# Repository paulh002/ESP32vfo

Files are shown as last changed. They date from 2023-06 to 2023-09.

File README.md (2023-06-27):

# ESP32vfo

Disclaimer -->  source code developement is in progress not all functions are migrated from the old version!

Source code for VFO-ESP32-Si5351 v3 
A new PCB size 10cm x 5.6 cm 4 layers this can be lowcost produced.
Supports 1 optical encoder and multiple rotary encoders through a pcf8574

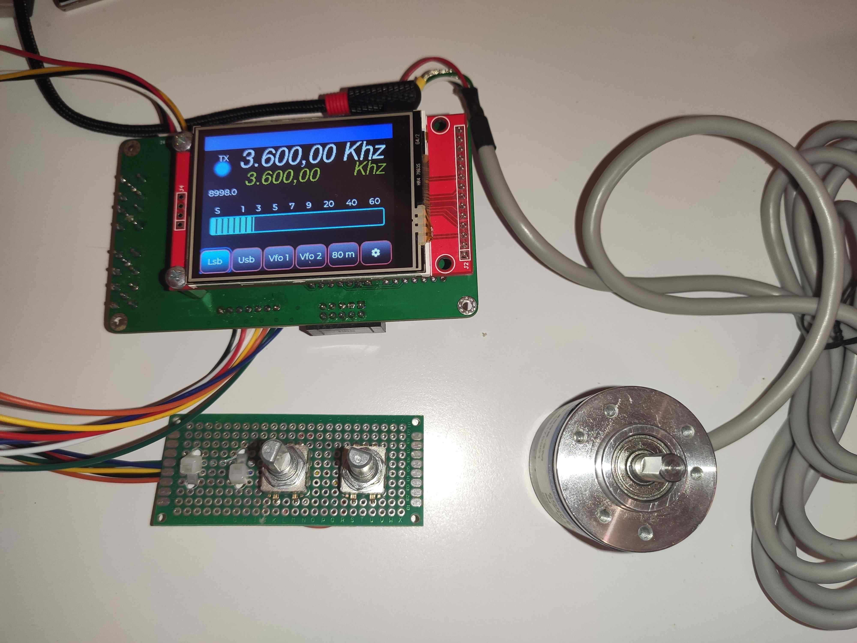
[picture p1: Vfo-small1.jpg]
VFO


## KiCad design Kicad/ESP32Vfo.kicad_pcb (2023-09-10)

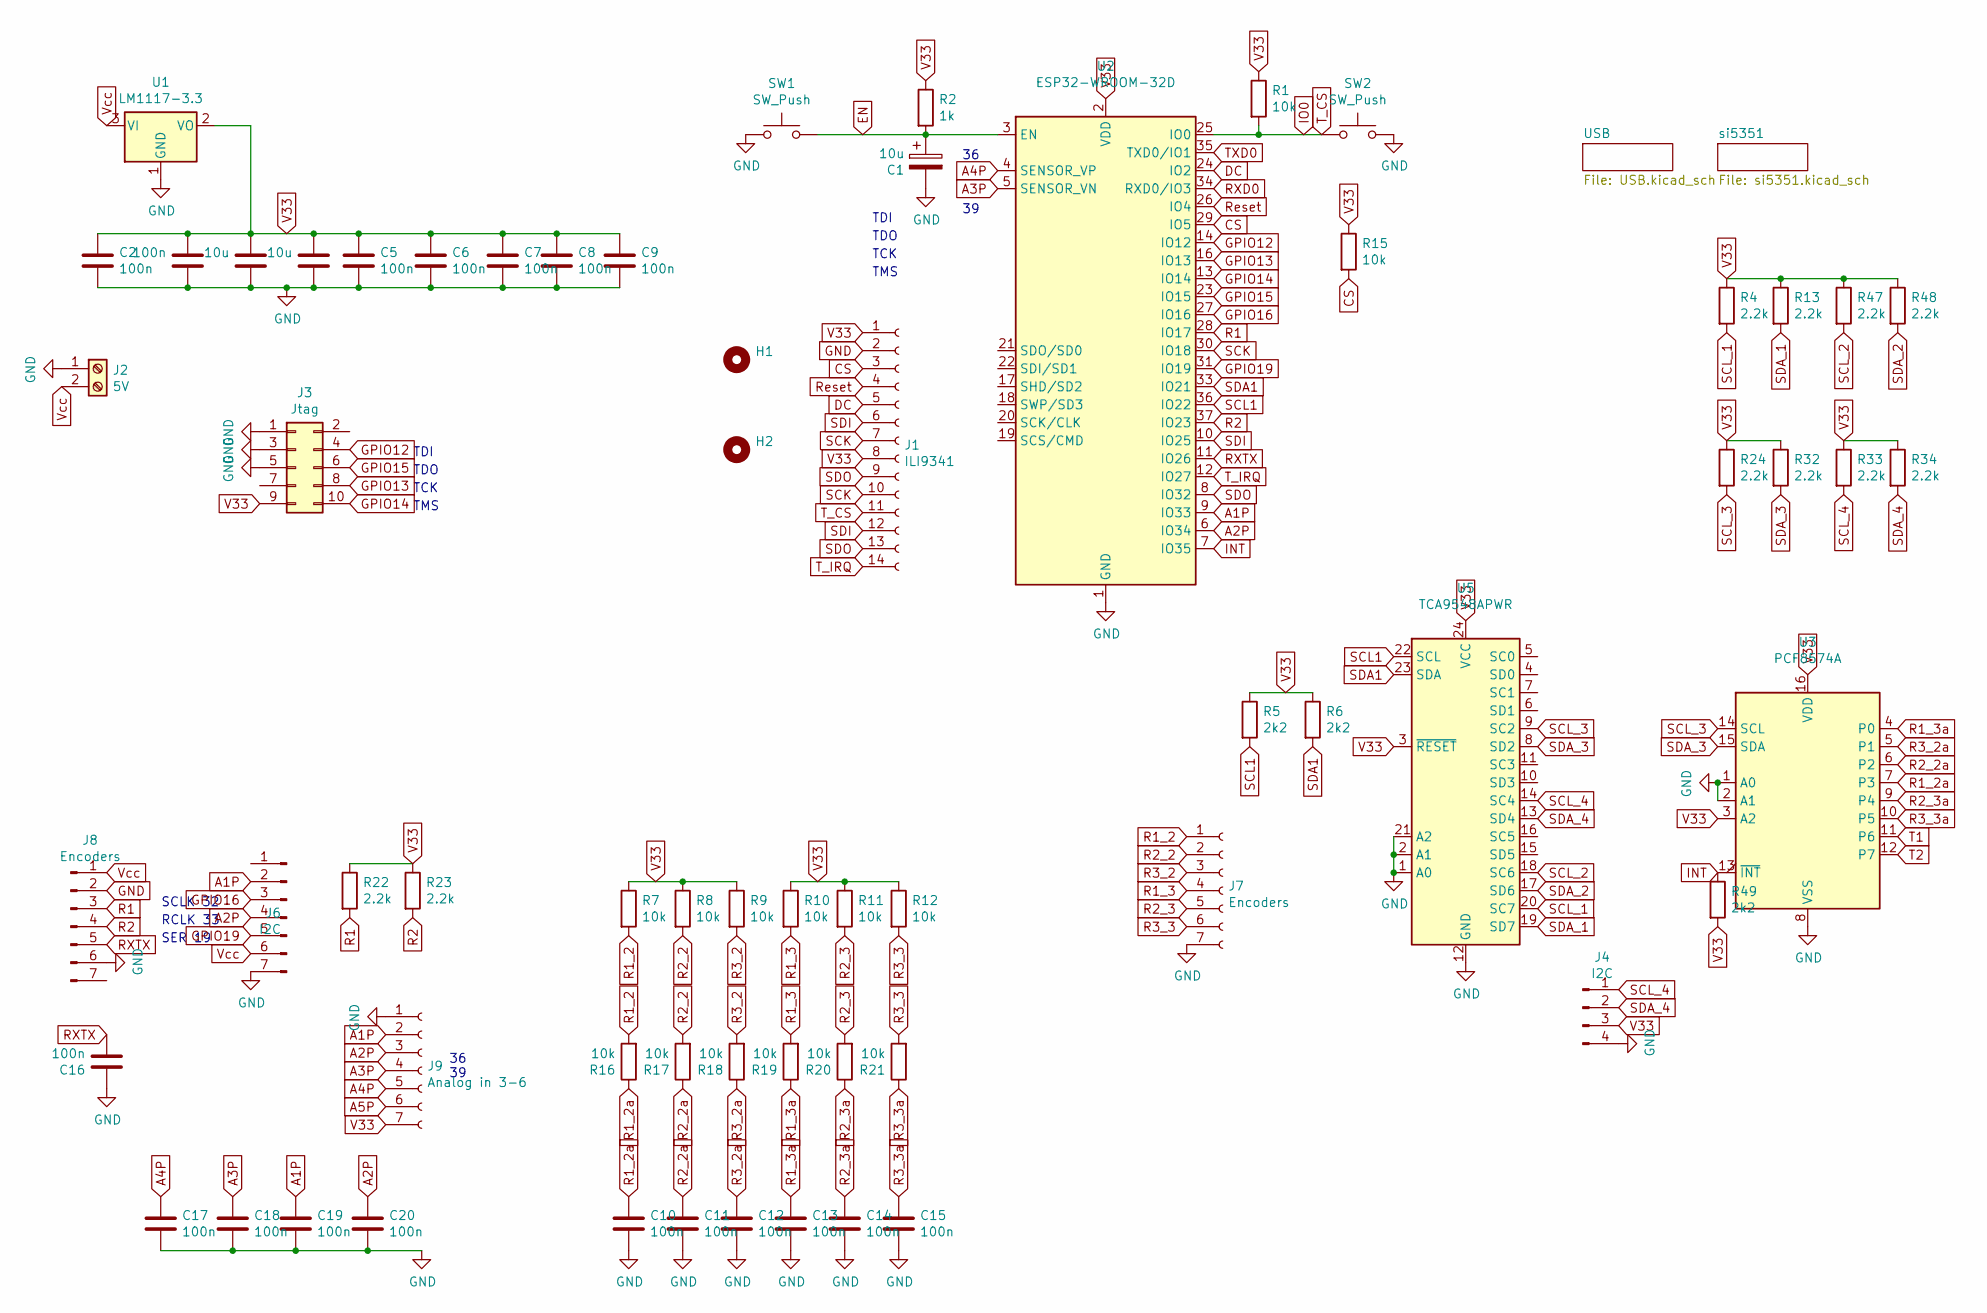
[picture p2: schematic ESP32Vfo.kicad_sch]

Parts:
C1, C4: 10u; C_1206_3216Metric_Pad1.42x1.75mm_HandSolder
C2, C3, C5, C6, C7, C8, C9, C10, C11, C12, C13, C14, C15, C16, C17, C18, C19, C20: 100n; C_0805_2012Metric
C34: 10u; C_0805_2012Metric
H1, H2: MountingHole_3.2mm_M3
J1: ILI9341; PinSocket_1x14_P2.54mm_Vertical
J2: 5V; TerminalBlock_MetzConnect_Type011_RT05502HBWC_1x02_P5.00mm_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
J3: Jtag; PinSocket_2x05_P2.54mm_Vertical
J4: I2C; JST_PH_S4B-PH-SM4-TB_1x04-1MP_P2.00mm_Horizontal
J6: I2C; PinSocket_1x07_P2.54mm_Vertical
J7, J8: Encoders; PinSocket_1x07_P2.54mm_Vertical
J9: Analog in 3-6; PinSocket_1x07_P2.54mm_Vertical
R1, R7, R8, R9, R10, R11, R12, R15, R16, R17, R18, R19, R20, R21: 10k; R_0805_2012Metric
R2: 1k; R_0805_2012Metric
R4, R13, R22, R23, R24, R32, R33, R34, R47, R48: 2.2k; R_0805_2012Metric
R5, R6, R49: 2k2; R_0805_2012Metric
SW1, SW2: SW_Push; TS-1088R-02526
U1: LM1117-3.3; SOT-223-3_TabPin2
U2: ESP32-WROOM-32D; ESP32-WROOM-32
U3: PCF8574A; SOP-16_7.5x10.4mm_P1.27mm
U5: TCA9548APWR; TSSOP-24_4.4x7.8mm_P0.65mm

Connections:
A1P: C19.2, J6.2, J9.2, U2.9 (IO33)
A2P: C20.2, J6.4, J9.3, U2.6 (IO34)
A3P: C18.2, J9.4, U2.5 (SENSOR_VN)
A4P: C17.2, J9.5, U2.4 (SENSOR_VP)
A5P: J9.6
CS: J1.3, R15.2, U2.29 (IO5)
DC: J1.5, U2.24 (IO2)
EN: C1.1, R2.2, SW1.2, U2.3 (EN); also elsewhere on the board
GND: C1.2, C2.1, C3.2, C4.2, C5.1, C6.1, C7.1, C8.1, C9.1, C10.1, C11.1, C12.1, C13.1, C14.1, C15.1, C16.2, C17.1, C18.1, C19.1, C20.1, C34.2, J1.2, J2.1, J3.1, J3.3, J3.5, J4.4, J6.7, J7.7, J8.2, J8.6, J9.1, SW1.1, SW2.2, U1.1 (GND), U2.1 (GND), U2.15 (GND), U2.38 (GND), U2.39 (GND), U3.1 (A0), U3.2 (A1), U3.8 (VSS), U5.1 (A0), U5.2 (A1), U5.12 (GND), U5.21 (A2); also elsewhere on the board
GPIO12: J3.4, U2.14 (IO12)
GPIO13: J3.8, U2.16 (IO13)
GPIO14: J3.10, U2.13 (IO14)
GPIO15: J3.6, U2.23 (IO15)
GPIO16: J6.3, U2.27 (IO16)
GPIO19: J6.5, U2.31 (IO19)
INT: R49.1, U2.7 (IO35), U3.13 (~INT)
IO0: J1.11, R1.2, SW2.1, U2.25 (IO0); also elsewhere on the board
R1: J8.3, R22.2, U2.28 (IO17)
R1_2: J7.1, R7.2, R16.2
R1_2a: C10.2, R16.1, U3.7 (P3)
R1_3: J7.4, R10.2, R19.2
R1_3a: C13.2, R19.1, U3.4 (P0)
R2: J8.4, R23.2, U2.37 (IO23)
R2_2: J7.2, R8.2, R17.2
R2_2a: C11.2, R17.1, U3.6 (P2)
R2_3: J7.5, R11.2, R20.2
R2_3a: C14.2, R20.1, U3.9 (P4)
R3_2: J7.3, R9.2, R18.2
R3_2a: C12.2, R18.1, U3.5 (P1)
R3_3: J7.6, R12.2, R21.2
R3_3a: C15.2, R21.1, U3.10 (P5)
RXD0: U2.34 (RXD0/IO3); also elsewhere on the board
RXTX: C16.1, J8.5, U2.11 (IO26); also elsewhere on the board
Reset: J1.4, U2.26 (IO4)
SCK: J1.7, J1.10, U2.30 (IO18)
SCL1: R5.2, U2.36 (IO22), U5.22 (SCL)
SCL_1: R4.2, U5.20 (SC7); also elsewhere on the board
SCL_2: R47.2, U5.18 (SC6); also elsewhere on the board
SCL_3: R24.2, U3.14 (SCL), U5.9 (SC2)
SCL_4: J4.1, R33.2, U5.14 (SC4)
SDA1: R6.2, U2.33 (IO21), U5.23 (SDA)
SDA_1: R13.2, U5.19 (SD7); also elsewhere on the board
SDA_2: R48.2, U5.17 (SD6); also elsewhere on the board
SDA_3: R32.2, U3.15 (SDA), U5.8 (SD2)
SDA_4: J4.2, R34.2, U5.13 (SD4)
SDI: J1.6, J1.12, U2.10 (IO25)
SDO: J1.9, J1.13, U2.8 (IO32)
T1: U3.11 (P6); also elsewhere on the board
T2: U3.12 (P7); also elsewhere on the board
TXD0: U2.35 (TXD0/IO1); also elsewhere on the board
T_IRQ: J1.14, U2.12 (IO27)
V33: C2.2, C3.1, C4.1, C5.2, C6.2, C7.2, C8.2, C9.2, C34.1, J1.1, J1.8, J3.9, J4.3, J9.7, R1.1, R2.1, R4.1, R5.1, R6.1, R7.1, R8.1, R9.1, R10.1, R11.1, R12.1, R13.1, R15.1, R22.1, R23.1, R24.1, R32.1, R33.1, R34.1, R47.1, R48.1, R49.2, U1.2 (VO), U2.2 (VDD), U3.3 (A2), U3.16 (VDD), U5.3 (~RESET), U5.24 (VCC); also elsewhere on the board
Vcc: J2.2, J6.6, J8.1, U1.3 (VI); also elsewhere on the board

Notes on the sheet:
TDI
TDO
TMS
RCLK 33
SER 19
TCK
36 39
SCLK 32

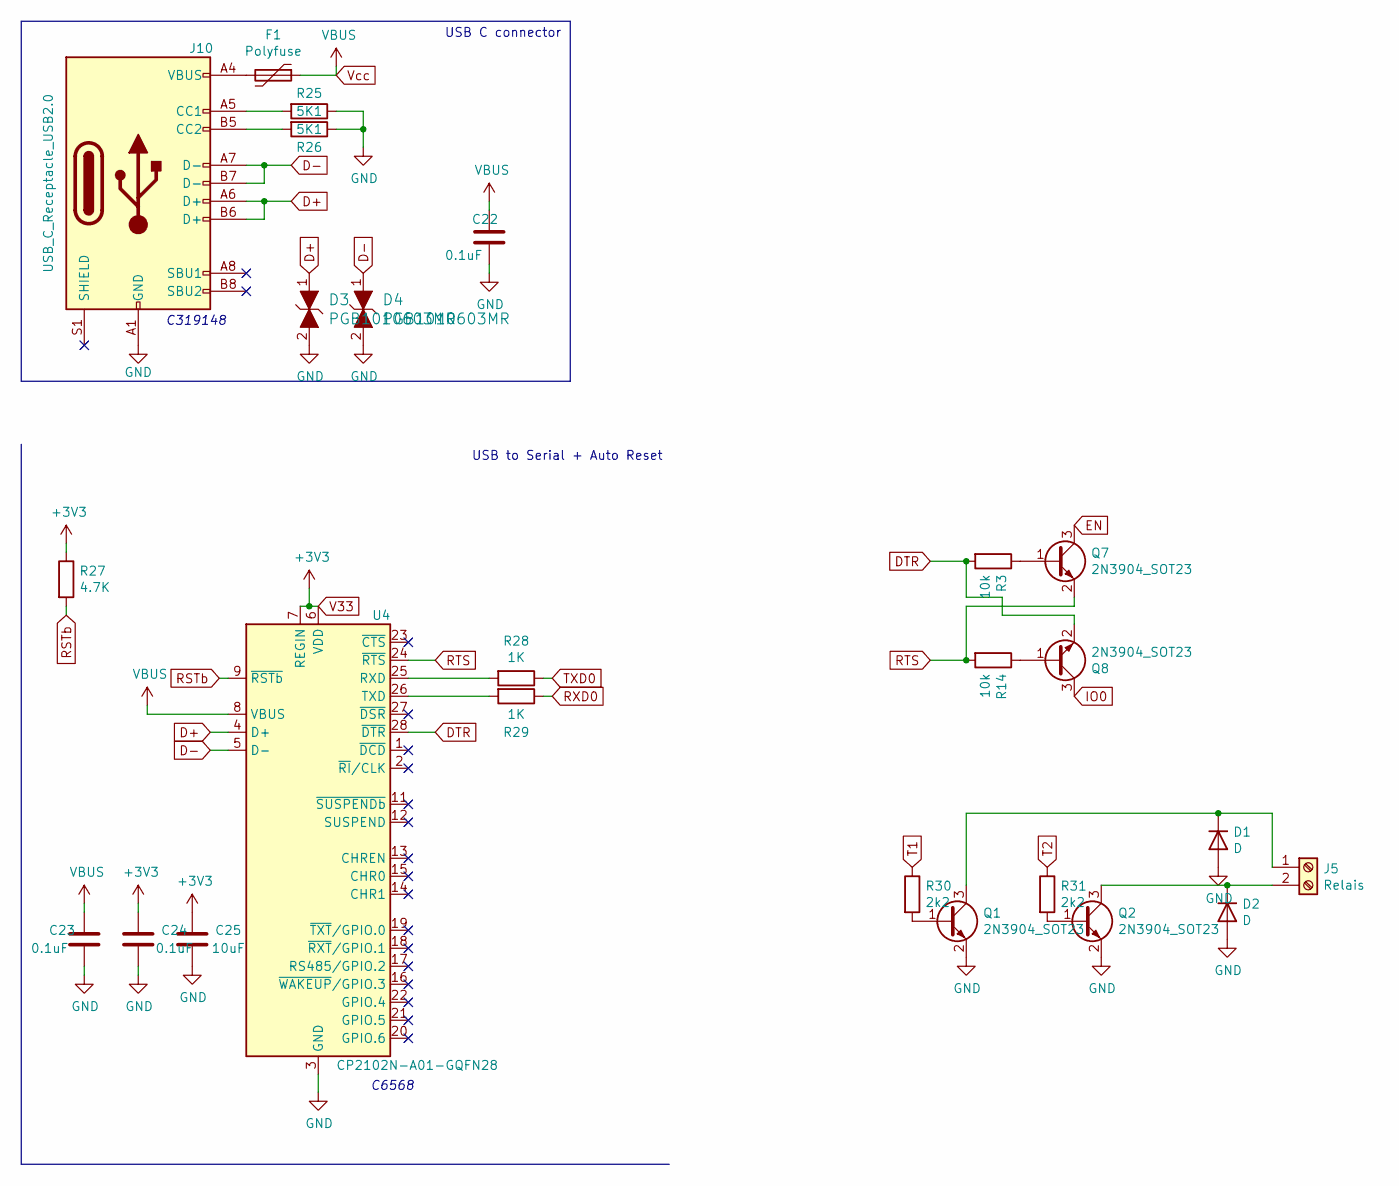
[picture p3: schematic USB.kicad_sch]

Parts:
C22, C23, C24: 0.1uF; C_0805_2012Metric
C25: 10uF; C_0805_2012Metric
D1, D2: D; D_SOD-323
D3, D4: PGB1010603MR; 0603; MPN PGB1010603MR; Digi-Key_PN F2594CT-ND
F1: Polyfuse; Fuse_0805_2012Metric
J5: Relais; PinHeader_1x02_P2.54mm_Vertical
J10: USB_C_Receptacle_USB2.0; USB_C_Receptacle_XKB_U262-16XN-4BVC11
Q1, Q2, Q7, Q8: 2N3904_SOT23; SOT-23
R3, R14: 10k; R_0805_2012Metric
R25, R26: 5K1; R_0805_2012Metric
R27: 4.7K; R_0805_2012Metric
R28, R29: 1K; R_0805_2012Metric
R30, R31: 2k2; R_0805_2012Metric
U4: CP2102N-A01-GQFN28; QFN-28-1EP_5x5mm_P0.5mm_EP3.35x3.35mm

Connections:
D+: D3.1, J10.A6 (D+), J10.B6 (D+), U4.4 (D+)
D-: D4.1, J10.A7 (D-), J10.B7 (D-), U4.5 (D-)
DTR: Q8.2 (E), R3.2, U4.28 (~DTR)
EN: Q7.3 (C); also elsewhere on the board
GND: C22.2, C23.2, C24.2, C25.2, D1.2 (A), D2.2 (A), D3.2, D4.2, J10.A1 (GND), J10.A12 (GND), J10.B1 (GND), J10.B12 (GND), Q1.2 (E), Q2.2 (E), R25.1, R26.1, U4.3 (GND), U4.29 (GND); also elsewhere on the board
IO0: Q8.3 (C); also elsewhere on the board
unnamed: D1.1 (K), J5.1, Q1.3 (C)
unnamed: D2.1 (K), J5.2, Q2.3 (C)
unnamed: F1.2, J10.A4 (VBUS), J10.A9 (VBUS), J10.B4 (VBUS), J10.B9 (VBUS)
unnamed: J10.A5 (CC1), R25.2
unnamed: J10.B5 (CC2), R26.2
unnamed: Q1.1 (B), R30.2
unnamed: Q2.1 (B), R31.2
unnamed: Q7.1 (B), R3.1
unnamed: Q8.1 (B), R14.1
unnamed: R28.2, U4.25 (RXD)
unnamed: R29.2, U4.26 (TXD)
RSTb: R27.2, U4.9 (~RSTb)
RTS: Q7.2 (E), R14.2, U4.24 (~RTS)
RXD0: R29.1; also elsewhere on the board
T1: R30.1; also elsewhere on the board
T2: R31.1; also elsewhere on the board
TXD0: R28.1; also elsewhere on the board
V33: C24.1, C25.1, R27.1, U4.6 (VDD), U4.7 (REGIN); also elsewhere on the board
Vcc: C22.1, C23.1, F1.1, U4.8 (VBUS); also elsewhere on the board

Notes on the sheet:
C319148
USB C connector
USB to Serial + Auto Reset
C6568

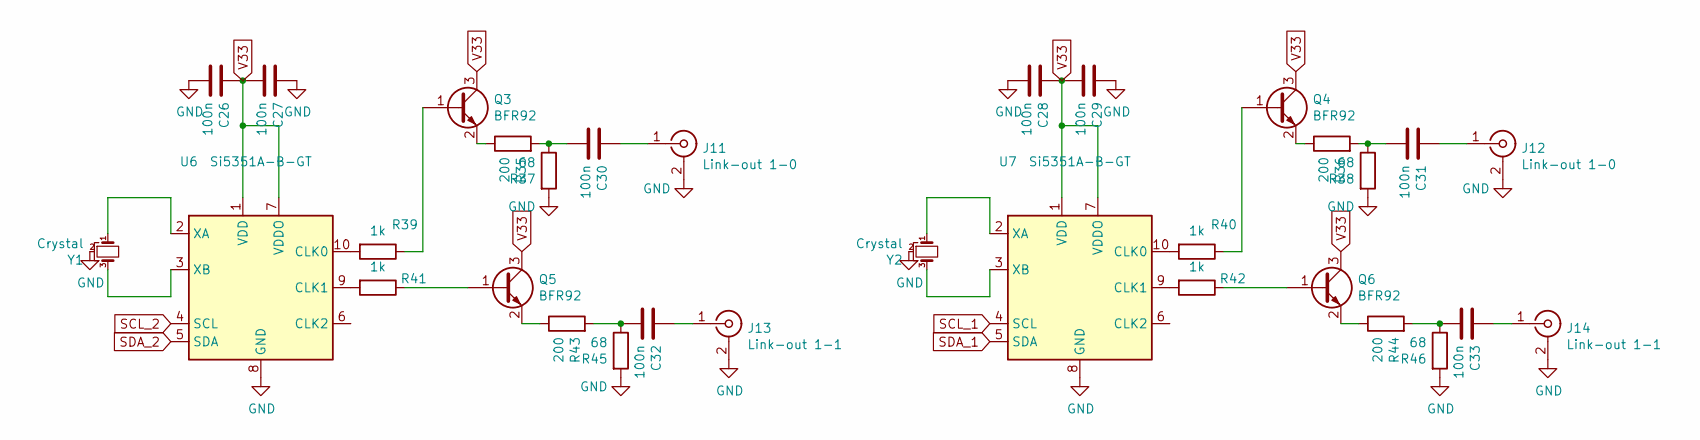
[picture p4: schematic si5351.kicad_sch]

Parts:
C26, C27, C28, C29, C30, C31, C32, C33: 100n; C_0805_2012Metric
J11, J12: Link-out 1-0; SMA_Amphenol_132134_Vertical
J13, J14: Link-out 1-1; SMA_Amphenol_132134_Vertical
Q3, Q4, Q5, Q6: BFR92; SOT-23
R35, R36, R43, R44: 200; R_0805_2012Metric
R37, R38, R45, R46: 68; R_0805_2012Metric
R39, R40, R41, R42: 1k; R_0805_2012Metric
U6, U7: Si5351A-B-GT; MSOP-10_3x3mm_P0.5mm
Y1, Y2: Crystal; Crystal_SMD_TXC_7M-4Pin_3.2x2.5mm_HandSoldering

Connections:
GND: C26.1, C27.2, C28.1, C29.2, J11.2 (Ext), J12.2 (Ext), J13.2 (Ext), J14.2 (Ext), R37.2, R38.2, R45.2, R46.2, U6.8 (GND), U7.8 (GND), Y1.2, Y2.2; also elsewhere on the board
unnamed: C30.1, R35.2, R37.1
unnamed: C30.2, J11.1 (In)
unnamed: C31.1, R36.2, R38.1
unnamed: C31.2, J12.1 (In)
unnamed: C32.1, R43.2, R45.1
unnamed: C32.2, J13.1 (In)
unnamed: C33.1, R44.2, R46.1
unnamed: C33.2, J14.1 (In)
unnamed: Q3.1 (B), R39.1
unnamed: Q3.2 (E), R35.1
unnamed: Q4.1 (B), R40.1
unnamed: Q4.2 (E), R36.1
unnamed: Q5.1 (B), R41.1
unnamed: Q5.2 (E), R43.1
unnamed: Q6.1 (B), R42.1
unnamed: Q6.2 (E), R44.1
unnamed: R39.2, U6.10 (CLK0)
unnamed: R40.2, U7.10 (CLK0)
unnamed: R41.2, U6.9 (CLK1)
unnamed: R42.2, U7.9 (CLK1)
unnamed: U6.2 (XA), Y1.1
unnamed: U6.3 (XB), Y1.3
unnamed: U7.2 (XA), Y2.1
unnamed: U7.3 (XB), Y2.3
SCL_1: U7.4 (SCL); also elsewhere on the board
SCL_2: U6.4 (SCL); also elsewhere on the board
SDA_1: U7.5 (SDA); also elsewhere on the board
SDA_2: U6.5 (SDA); also elsewhere on the board
V33: C26.2, C27.1, C28.2, C29.1, Q3.3 (C), Q4.3 (C), Q5.3 (C), Q6.3 (C), U6.1 (VDD), U6.7 (VDDO), U7.1 (VDD), U7.7 (VDDO); also elsewhere on the board

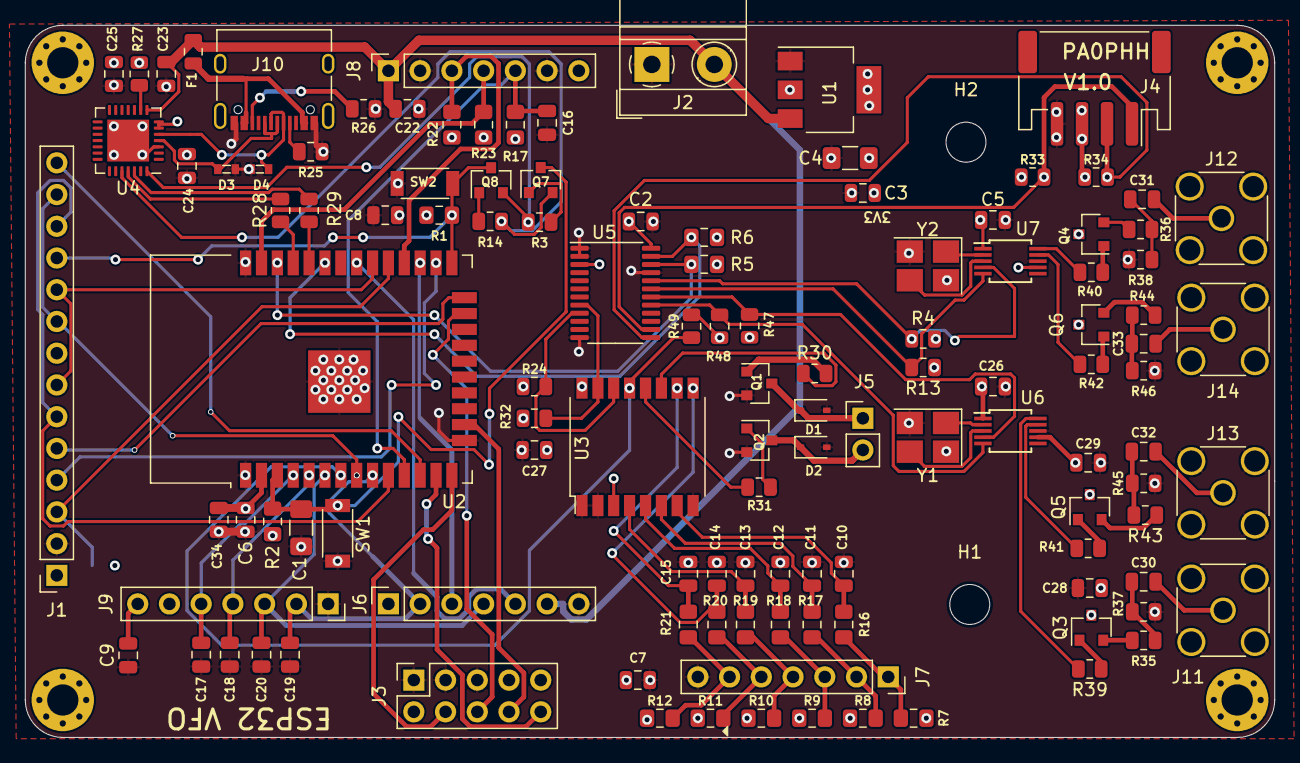
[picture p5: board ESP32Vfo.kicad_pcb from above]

Board: 4 copper layers, 100.0 x 57.0 mm, 127 parts (1 on the bottom side), 92 nets.

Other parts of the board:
H1#2, H2#2: MountingHole_3.2mm_M3
H3, H4: MountingHole; MountingHole_2.5mm_Pad_Via
R17#2: 680; R_0805_2012Metric_Pad1.15x1.40mm_HandSolder

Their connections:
RXTX: R17#2.2; also elsewhere on the board
V33: R17#2.1; also elsewhere on the board

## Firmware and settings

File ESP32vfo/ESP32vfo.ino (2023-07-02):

/*
 Name:		ESP32vfo.ino
 Created:	11/14/2021 1:09:05 PM
 Author:	paulh
*/
#include <WiFi.h>
#include <WiFiClient.h>
#include <lvgl.h>
#include <TFT_eSPI.h>
#include <TCA9548.h>
#include <RotaryEncoder.h>
#include "gui.h"
#include "credentials.h"
#include "measurement.h"
#include "network.h"
#include "io.h"
#include "vfo.h"
#include "_EEPROMAnything.h"
#include "FT891_CAT.h"

SemaphoreHandle_t swrBinarySemaphore = NULL;
SemaphoreHandle_t NetSemaphore = NULL;

#define COLDSTART_REF          0x20 // When started, the firmware examines this "Serial Number
// and enforces factory reset if there is a mismatch.
// Rolling this value is useful if the EEPROM structure has been modified

TFT_eSPI tft = TFT_eSPI(); /* TFT instance */

extern var_t	R;

// the setup function runs once when you press reset or power the board
void setup() {
	Serial.begin(115200); /* prepare for possible serial debug */
	swrBinarySemaphore = xSemaphoreCreateMutex();
	if (swrBinarySemaphore == NULL) {
		Serial.println("Error creating the swrBinarySemaphore");
	}
	net_queue = xQueueCreate(1, sizeof(uint8_t));
	if (net_queue == NULL) {
		Serial.println("Error creating the queue");
	}

	pinMode(TXRX_SWITCH, INPUT);
	pinMode(S_METER, ANALOG);
	pinMode(FWD_METER, ANALOG);
	pinMode(REV_METER, ANALOG);
	adc_init();
	memset(&R, 0, sizeof(R));
	init_io();
	init_vfo(); // load default values for R
	CAT.begin(true);
	start_vfo();
	LoadEEPROM();
	gui.gui_setup();

	R.wifi_onoff = true;
	delay(10);
	if (strlen(R.ssid[0]) == 0) // If no ssid configured take from credentials.h
	{
		for (int i = 0; i < NUMBR_SSID; i++)
		{
			strcpy(R.ssid[i], _ssid[i]);
			strcpy(R.password[i], _password[i]);
		}
	}
	if (R.wifi_onoff)
	{
		for (int i = 0; i < NUMBR_SSID; i++)
		{
			if (strlen(R.ssid[i]))
			{
				Serial.println("Start Wifi");
				if (vfo_network.begin(TRXNET_SERVER))
				{
					return;
				}
			}
		}
	}
}

// the loop function runs over and over again until power down or reset
void loop() {

	if (net_queue)
	{ // Check if we need to start or stop wifi
		uint8_t message;
		if (xQueueReceive(net_queue, &message, 0))
		{
			if (message == 0)
			{
				// stopwifi
				vfo_network.network_stop();
			}
			if (message == 1)
			{
				// startwifi
				vfo_network.begin(TRXNET_SERVER);
			}
		}
	}
	vfo_network.network_loop();
	delay(5);
}


void LoadEEPROM()
{
	uint8_t coldstart;

	EEPROM.begin(sizeof(var_t) + sizeof(uint8_t));

	coldstart = EEPROM.read(0);               // Grab the coldstart byte indicator in EEPROM for
											   // comparison with the COLDSTART_REFERENCE

	Serial.println(String("Coldstart : ") + String(coldstart));

	// Initialize all memories if first upload or if COLDSTART_REF has been modified
	// either through PSWR_A.h or through Menu functions

	if (coldstart == COLDSTART_REF - 1)
	{

		EEPROM_readAnything(1, R);               // Read the stored data
		long  current_frq1[] = { 1800000,3500000,5350000,7000000,10100000,14000000,18068000,21000000,28000000 };
		long  current_frq2[] = { 1800000,3500000,5350000,7000000,10100000,14000000,18068000,21000000,28000000 };

		memcpy(R.current_frq1, current_frq1, sizeof(current_frq1));
		memcpy(R.current_frq2, current_frq2, sizeof(current_frq2));
		return;
	}

	if (coldstart != COLDSTART_REF)
	{
		EEPROM.write(0, COLDSTART_REF);          // COLDSTART_REF in first byte indicates all initialized
		EEPROM_writeAnything(1, R);              // Write default settings into EEPROM
		EEPROM.commit();
	}
	else                                      // EEPROM contains stored data, retrieve the data
	{
		EEPROM_readAnything(1, R);               // Read the stored data
	}
}

void SaveEEPROM()
{
	EEPROM.write(0, COLDSTART_REF);          // COLDSTART_REF in first byte indicates all initialized
	EEPROM_writeAnything(1, R);              // Write default settings into  
	EEPROM.commit();
}

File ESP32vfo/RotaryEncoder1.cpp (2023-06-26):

// -----
// RotaryEncoder.cpp - Library for using rotary encoders.
// This class is implemented for use with the Arduino environment.
//
// Copyright (c) by Matthias Hertel, http://www.mathertel.de
//
// This work is licensed under a BSD 3-Clause style license,
// https://www.mathertel.de/License.aspx.
//
// More information on: http://www.mathertel.de/Arduino
// -----
// Changelog: see RotaryEncoder.h
// -----

#include "RotaryEncoder1.h"
#include "Arduino.h"

#define LATCH0 0 // input state at position 0
#define LATCH3 3 // input state at position 3


// The array holds the values �1 for the entries where a position was decremented,
// a 1 for the entries where the position was incremented
// and 0 in all the other (no change or not valid) cases.

const int8_t KNOBDIR[] = {
    0, -1, 1, 0,
    1, 0, 0, -1,
    -1, 0, 0, 1,
    0, 1, -1, 0};


// positions: [3] 1 0 2 [3] 1 0 2 [3]
// [3] is the positions where my rotary switch detends
// ==> right, count up
// <== left,  count down


// ----- Initialization and Default Values -----

RotaryEncoder::RotaryEncoder(uint8_t address, uint8_t cnt, LatchMode mode, TwoWire* wire)
{
  // Remember Hardware Setup
  _address = address;
  _mode = mode;
  _cnt = cnt;

  // Setup wire
  _wire = wire;
  for (int i = 0; i < max_enc; i++)
  {
      // start with position 0;
      // when not started in motion, the current state of the encoder should be 3
      _oldState[i] = 0x03;
      _position[i] = 0;
      _positionExt[i] = 0;
      _positionExtPrev[i] = 0;
  }
} // RotaryEncoder()


long RotaryEncoder::getPosition(int enc)
{
    if (enc >= 0 && enc < _cnt)
        return _positionExt[enc];
    return -1;
} // getPosition()


RotaryEncoder::Direction RotaryEncoder::getDirection(int enc)
{
  RotaryEncoder::Direction ret = Direction::NOROTATION;
  if (enc >= 0 && enc < _cnt)
  {
      if (_positionExtPrev[enc] > _positionExt[enc]) {
          ret = Direction::COUNTERCLOCKWISE;
          _positionExtPrev[enc] = _positionExt[enc];
      }
      else if (_positionExtPrev[enc] < _positionExt[enc]) {
          ret = Direction::CLOCKWISE;
          _positionExtPrev[enc] = _positionExt[enc];
      }
      else {
          ret = Direction::NOROTATION;
          _positionExtPrev[enc] = _positionExt[enc];
      }
  }
  return ret;
}


void RotaryEncoder::setPosition(int enc, long newPosition)
{
    if (enc >= 0 && enc < _cnt)
    {
        switch (_mode) {
        case LatchMode::FOUR3:
        case LatchMode::FOUR0:
            // only adjust the external part of the position.
            _position[enc] = ((newPosition << 2) | (_position[enc] & 0x03L));
            _positionExt[enc] = newPosition;
            _positionExtPrev[enc] = newPosition;
            break;

        case LatchMode::TWO03:
            // only adjust the external part of the position.
            _position[enc] = ((newPosition << 1) | (_position[enc] & 0x01L));
            _positionExt[enc] = newPosition;
            _positionExtPrev[enc] = newPosition;
            break;
        } // switch
    }
} // setPosition()


void RotaryEncoder::tick(void)
{
  uint8_t val = _read8();
  int8_t thisState;
  for (int i = 0; i < _cnt; i++)
  {
      switch (i)
      {
      case 0:
          thisState = (val & 0x01) | (val & 0x02);
          break;
      case 1:
          thisState = (val & 0x04) | (val & 0x08);
          thisState = thisState >> 2;
          break;
      case 2:
          thisState = (val & 0x10) | (val & 0x20);
          thisState = thisState >> 4;
          break;
      case 3:
          thisState = (val & 0x40) | (val & 0x80);
          thisState = thisState >> 6;
          break;
      }
      if (_oldState[i] != thisState) {
          _position[i] += KNOBDIR[thisState | (_oldState[i] << 2)];
          _oldState[i] = thisState;

          switch (_mode) {
          case LatchMode::FOUR3:
              if (thisState == LATCH3) {
                  // The hardware has 4 steps with a latch on the input state 3
                  _positionExt[i] = _position[i] >> 2;
                  _positionExtTimePrev[i] = _positionExtTime[i];
                  _positionExtTime[i] = millis();
              }
              break;

          case LatchMode::FOUR0:
              if (thisState == LATCH0) {
                  // The hardware has 4 steps with a latch on the input state 0
                  _positionExt[i] = _position[i] >> 2;
                  _positionExtTimePrev[i] = _positionExtTime[i];
                  _positionExtTime[i] = millis();
              }
              break;

          case LatchMode::TWO03:
              if ((thisState == LATCH0) || (thisState == LATCH3)) {
                  // The hardware has 2 steps with a latch on the input state 0 and 3
                  _positionExt[i] = _position[i] >> 1;
                  _positionExtTimePrev[i] = _positionExtTime[i];
                  _positionExtTime[i] = millis();
              }
              break;
          } // switch
      } // if
  } // for
} // tick()


unsigned long RotaryEncoder::getMillisBetweenRotations(int enc) const
{
  return (_positionExtTime[enc] - _positionExtTimePrev[enc]);
}

unsigned long RotaryEncoder::getRPM(int enc)
{
  // calculate max of difference in time between last position changes or last change and now.
  unsigned long timeBetweenLastPositions = _positionExtTime[enc] - _positionExtTimePrev[enc];
  unsigned long timeToLastPosition = millis() - _positionExtTime[enc];
  unsigned long t = max(timeBetweenLastPositions, timeToLastPosition);
  return 60000.0 / ((float)(t * 20));
}

uint8_t RotaryEncoder::_read8()
{
    _wire->requestFrom(_address, (uint8_t)1);
    uint8_t val = _wire->read();
    if (_buttonports[0] < 8)
    {
        if (val & (1 << _buttonports[0]))
            _pressed[0] = false;
        else
            _pressed[0] = true;
    }
    if (_buttonports[1] < 8)
    {
        if (val & (1 << _buttonports[1]))
            _pressed[1] = false;
        else
            _pressed[1] = true;
    }
    return  val & 0x0F;
}

bool RotaryEncoder::isConnected()
{
    _wire->beginTransmission(_address);
    return (_wire->endTransmission() == 0);
}

void RotaryEncoder::setButtonPorts(uint8_t b1, uint8_t b2)
{
    if (b1 >= 0 || b1 < 8)
        _buttonports[0] = b1;

    if (b2 >= 0 || b2 < 8)
        _buttonports[1] = b2;
}
// End

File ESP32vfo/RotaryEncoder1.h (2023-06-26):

// -----
// RotaryEncoder.h - Library for using rotary encoders.
// This class is implemented for use with the Arduino environment.
//
// Copyright (c) by Matthias Hertel, http://www.mathertel.de
//
// This work is licensed under a BSD 3-Clause style license,
// https://www.mathertel.de/License.aspx.
//
// More information on: http://www.mathertel.de/Arduino
// -----
// 18.01.2014 created by Matthias Hertel
// 16.06.2019 pin initialization using INPUT_PULLUP
// 10.11.2020 Added the ability to obtain the encoder RPM
// 29.01.2021 Options for using rotary encoders with 2 state changes per latch.
// -----

#ifndef RotaryEncoder_h
#define RotaryEncoder_h

#include "Arduino.h"
#include "Wire.h"

const int max_enc = 4;

class RotaryEncoder
{
public:
  enum class Direction {
    NOROTATION = 0,
    CLOCKWISE = 1,
    COUNTERCLOCKWISE = -1
  };

  enum class LatchMode {
    FOUR3 = 1, // 4 steps, Latch at position 3 only (compatible to older versions)
    FOUR0 = 2, // 4 steps, Latch at position 0 (reverse wirings)
    TWO03 = 3  // 2 steps, Latch at position 0 and 3 
  };

  // ----- Constructor -----
  RotaryEncoder(uint8_t address, uint8_t cnt = 2, LatchMode mode = LatchMode::FOUR0, TwoWire* wire = &Wire);

  // retrieve the current position
  long getPosition(int enc);

  // simple retrieve of the direction the knob was rotated last time. 0 = No rotation, 1 = Clockwise, -1 = Counter Clockwise
  Direction getDirection(int enc);

  // adjust the current position
  void setPosition(int enc, long newPosition);

  // call this function every some milliseconds or by using an interrupt for handling state changes of the rotary encoder.
  void tick(void);

  // Returns the time in milliseconds between the current observed
  unsigned long getMillisBetweenRotations(int enc) const;

  // Returns the RPM
  unsigned long getRPM(int enc);

  void	  setButtonPorts(uint8_t b1, uint8_t b2);
  bool    isConnected();

private:
  uint8_t   _address; // PCF8574 address
  TwoWire*  _wire;
  LatchMode _mode; // Latch mode from initialization
  uint8_t	_buttonports[2] = { 255, 255 };
  bool		_pressed[2] = { false, false };
  uint8_t   _cnt;
  
  volatile  int8_t _oldState[max_enc];

  volatile  long _position[max_enc];        // Internal position (4 times _positionExt)
  volatile  long _positionExt[max_enc];     // External position
  volatile  long _positionExtPrev[max_enc]; // External position (used only for direction checking)

  unsigned  long _positionExtTime[max_enc];     // The time the last position change was detected.
  unsigned  long _positionExtTimePrev[max_enc]; // The time the previous position change was detected.

  uint8_t   _read8();
 
};

#endif

// End

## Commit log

2023-06-28 move kicad files
    [ESP32Vfo-B_Cu.gbl, ESP32Vfo-B_Mask.gbs, ESP32Vfo-B_Paste.gbp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]
2023-07-01 add power and swr screen
2023-07-02 fix bandpass filter
2023-09-10 pcb update
    [ESP32Vfo-B_Cu.gbl, ESP32Vfo-B_Mask.gbs, ESP32Vfo-B_Paste.gbp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]
